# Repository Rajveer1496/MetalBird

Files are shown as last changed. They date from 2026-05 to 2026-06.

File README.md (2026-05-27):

# Current State of Project

### Flight Controller PCB:

<div align="center">

**Top Layer**

<table border="0" cellspacing="0" cellpadding="10">
  <tr>
    <td align="center">
      
    </td>
    <td align="center">
      sm_red_top
    </td>
  </tr>
</table>

---

**Bottom Layer**

<table border="0" cellspacing="0" cellpadding="10">
  <tr>
    <td align="center">
      
    </td>
    <td align="center">
      sm_red_bottom
    </td>
  </tr>
</table>

---

### Flight Controller Schematic:

Schematic

</div>

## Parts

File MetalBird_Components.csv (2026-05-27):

Reference | Qty | Value | Footprint | Link | Datasheet
C1,C3,C4,C6,C8,C16,C22,C23,C25,C18,C20,C1A1 | 12 | 0.1μF | Capacitor_SMD:C_0603_1608Metric | https://www.mouser.in/ProductDetail/YAGEO/CC0603MRY5V9BB104?qs=sGAEpiMZZMuMW9TJLBQkXsl6q5ZT3drfxOCCtIk2mic%3D |  | https://www.amazon.in/Capacitor-36values20pcs-Electronic-Multiplayer-Capacitors/dp/B06XDG3WQX
C5 | 1 | 1nF / 1000pF | Capacitor_SMD:C_0603_1608Metric | https://www.mouser.in/ProductDetail/KYOCERA-AVX/KAM15AR71H102KM
C7 | 1 | 6.8nF / 6800pF | Capacitor_SMD:C_0603_1608Metric | https://www.mouser.in/ProductDetail/Murata-Electronics/GCM188R72A682MA37D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
C9 | 1 | 2.2μF | Capacitor_SMD:C_0603_1608Metric | https://www.mouser.in/ProductDetail/TAIYO-YUDEN/JMK107B7225KAHTR
C10,C12 | 2 | 20pF | Capacitor_SMD:C_0603_1608Metric | https://www.mouser.in/ProductDetail/KEMET/C0603C200G4HACTU?qs=sGAEpiMZZMuMW9TJLBQkXvqpoCCiVPPiX4wV0EC9Nf4%3D
C11,C15 | 2 | 1μF | Capacitor_SMD:C_0603_1608Metric | https://www.mouser.in/ProductDetail/Murata-Electronics/GRM188R61C105KA12D
C13 | 1 | 10pF | Capacitor_SMD:C_0603_1608Metric | https://www.mouser.in/ProductDetail/Vishay-Vitramon/VJ0603A100JXACW1BC
C17 | 1 | 10nF / 0.01μF | Capacitor_SMD:C_0603_1608Metric | https://www.mouser.in/ProductDetail/YAGEO/CC0603KPX7R7BB103
C21 | 1 | 2.2nF / 2200pF | Capacitor_SMD:C_0603_1608Metric | https://www.mouser.in/ProductDetail/KEMET/C0603C222K5RACAUTO7411
C2,C2A1,C14,C19 | 4 | 22µF | Capacitor_SMD:C_1206_3216Metric | https://www.mouser.in/ProductDetail/Samsung-Electro-Mechanics/CL31A226MOCLNNC
C24 | 1 | 100μF | Capacitor_SMD:C_1206_3216Metric | https://www.mouser.in/ProductDetail/Murata-Electronics/GRM31CR61A107MEA8K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
D1,D2 | 2 | LED | LED_SMD:LED_0603_1608Metric | https://robu.in/?s=0603+led&post_type=product
J1 | 1 | Battery Conn | Connector_JST:JST_PH_B2B-PH-K_1x02_P2.00mm_Vertical | https://www.mouser.in/ProductDetail/306-B2BPHKLFSN
J2 | 1 | SWD | Connector_PinHeader_2.54mm:PinHeader_1x04_P2.54mm_Vertical | https://robu.in/product/361030130sg111901-jiln-2-54x3-0machined-pin-header-1x30p-180-l11-96-upper-pinpoint0-60-bottom-pinpoint0-50-au1u-pps/
J3 | 1 | ESC1 | Connector_PinHeader_2.54mm:PinHeader_1x03_P2.54mm_Vertical
J4 | 1 | ESC2 | Connector_PinHeader_2.54mm:PinHeader_1x03_P2.54mm_Vertical
J5 | 1 | ESC3 | Connector_PinHeader_2.54mm:PinHeader_1x03_P2.54mm_Vertical
J6 | 1 | ESC4 | Connector_PinHeader_2.54mm:PinHeader_1x03_P2.54mm_Vertical
J7 | 1 | ELRS Reciver | Connector_PinHeader_2.54mm:PinHeader_1x04_P2.54mm_Vertical
J8 | 1 | USB/UART DEBUG | Connector_PinHeader_2.54mm:PinHeader_1x04_P2.54mm_Vertical
J9 | 1 | Camera Conn | Connector_PinHeader_2.54mm:PinHeader_1x03_P2.54mm_Vertical
J10 | 1 | VTX Conn | Connector_PinHeader_2.54mm:PinHeader_1x03_P2.54mm_Vertical
L1 | 1 | 2.2µH | Inductor_SMD:L_Cenker_CKCS4018 | https://www.mouser.in/ProductDetail/Bourns/SRN4018-2R2M?qs=UvjENeDOEeeZshE%252B%2FY2s8w%3D%3D
MP2331H1 | 1 | ~ | Package_TO_SOT_SMD:SOT-583-8 | https://www.mouser.in/ProductDetail/946-MP2331HGTL-P
Q1 | 1 | PMOS | Package_TO_SOT_SMD:SOT-23 | https://www.mouser.in/ProductDetail/637-MMFTP3401-AQ
R1 | 1 | 604kΩ | Resistor_SMD:R_0603_1608Metric | https://www.mouser.in/ProductDetail/YAGEO/AC0603FR-07604KL
R2,R4,R6 | 3 | 10kΩ | Resistor_SMD:R_0603_1608Metric | https://sharvielectronics.com/product/10k-ohm-1-10-watt-smd-resistor-1-tolerance-rc0603fr-0710kl-0603-package/
R3 | 1 | 20ohm | Resistor_SMD:R_0603_1608Metric | https://www.mouser.in/ProductDetail/YAGEO/RC0603JR-7W20RL
R5 | 1 | 7.68kΩ | Resistor_SMD:R_0603_1608Metric | https://www.mouser.in/ProductDetail/YAGEO/RC0603FR-077K68L
R7 | 1 | 40.2kΩ | Resistor_SMD:R_0603_1608Metric | https://www.mouser.in/ProductDetail/YAGEO/AC0603FR-0740K2L?qs=sGAEpiMZZMtlubZbdhIBIG07xJe44c5AHpWSQ6yK7z4%3D
R8 | 1 | 10K | Resistor_SMD:R_0603_1608Metric | https://sharvielectronics.com/product/10k-ohm-1-10-watt-smd-resistor-1-tolerance-rc0603fr-0710kl-0603-package/
R11 | 1 | 30.9K | Resistor_SMD:R_0603_1608Metric | https://www.mouser.in/ProductDetail/Panasonic/ERJ-PA3D3092V?qs=sGAEpiMZZMtlubZbdhIBIL24R7XL4VFWF2hXjANGU5E%3D
R12 | 1 | 20K | Resistor_SMD:R_0603_1608Metric | https://www.mouser.in/ProductDetail/YAGEO/RT0603FRD0720KL?qs=sGAEpiMZZMtlubZbdhIBIKm0gsRX2fVkuOFal8xbqgw%3D
R13,R14 | 2 | 150 | Resistor_SMD:R_0603_1608Metric | https://sharvielectronics.com/product/150-ohm-1-4w-smd-resistor-pack-of-20-smd-0603/
R15,R16,R17 | 3 | 4.7 K | Resistor_SMD:R_0603_1608Metric | https://sharvielectronics.com/product/4-7k-ohm-1-10-watt-resistor-1-tolerance-0603saf4701t5e-0603-package/
SW1 | 1 | SW_Push_Open | Button_Switch_SMD:SW_SPST_PTS645Sx43SMTR92 | https://www.mouser.in/ProductDetail/506-FSM2JSMATR
U1 | 1 | STM32F411CEUx | Package_DFN_QFN:QFN-48-1EP_7x7mm_P0.5mm_EP5.6x5.6mm | https://robu.in/product/stm32f411ceu6-st-arm-m4-100mhz-ufqfpn-487x7-microcontrollers-mcu-mpu-soc-rohs/
U2 | 1 | AMS1117-3.3 | Package_TO_SOT_SMD:SOT-223-3_TabPin2 | https://robu.in/product/ams1117-3-3v-1a-sot-223-voltage-regulator-ic-pack-of-5-ics/
U3 | 1 | MPU-6050 | Sensor_Motion:InvenSense_QFN-24_4x4mm_P0.5mm | https://robu.in/product/mpu-6050-qfn-24-3-axis-gyro-accelerometer-ic/
U4 | 1 | BMP280 | Package_LGA:Bosch_LGA-8_2x2.5mm_P0.65mm_ClockwisePinNumbering | https://robu.in/product/bmp280-barometric-pressure-and-altitude-sensor-i2c-spi-module/ |  | https://www.mouser.in/ProductDetail/262-BME280
Y1 | 1 | 8MHz | Crystal:Crystal_SMD_3225-4Pin_3.2x2.5mm | https://www.mouser.in/ProductDetail/ECS/ECS-80-12-33-JGN-TR?qs=d0WKAl%252BL4KaVcQK0q%252BTt4Q%3D%3D

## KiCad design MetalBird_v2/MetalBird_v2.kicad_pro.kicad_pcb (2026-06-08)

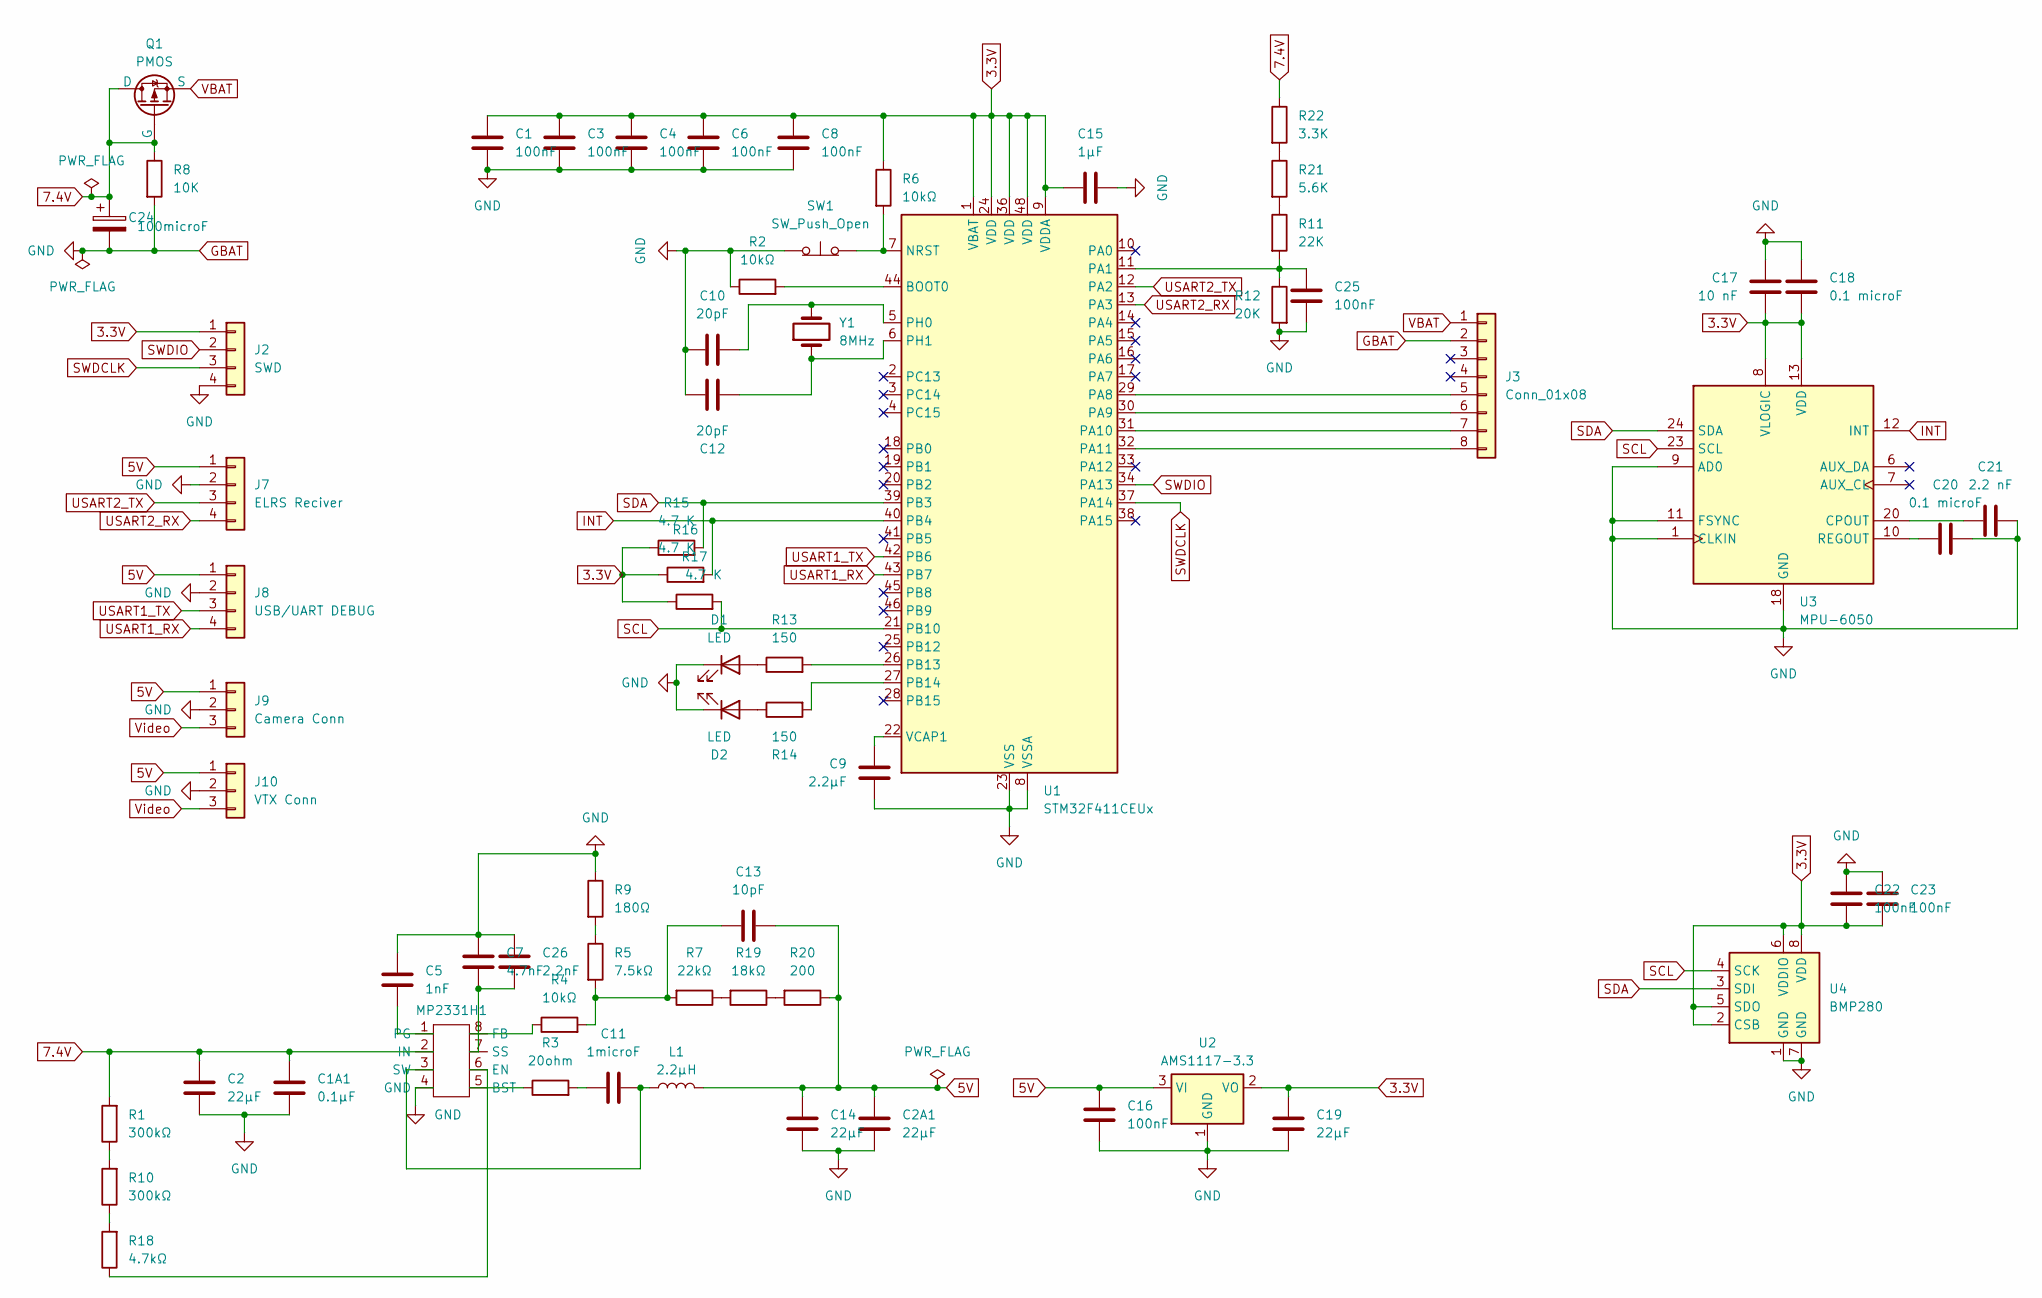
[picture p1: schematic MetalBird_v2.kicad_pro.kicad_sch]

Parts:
C1, C3, C4, C6, C8, C16, C22, C23, C25: 100nF; C_0603_1608Metric
C1A1: 0.1µF; C_0603_1608Metric
C2, C2A1, C14, C19: 22µF; C_1206_3216Metric
C5: 1nF; C_0603_1608Metric
C7: 4.7nF; C_0603_1608Metric
C9: 2.2μF; C_0603_1608Metric
C10, C12: 20pF; C_0603_1608Metric
C11: 1microF; C_0603_1608Metric
C13: 10pF; C_0603_1608Metric
C15: 1μF; C_0603_1608Metric
C17: 10 nF; C_0603_1608Metric
C18, C20: 0.1 microF; C_0603_1608Metric
C21: 2.2 nF; C_0603_1608Metric
C24: 100microF; C_1206_3216Metric
C26: 2.2nF; C_0603_1608Metric
D1, D2: LED; LED_0603_1608Metric
J2: SWD; PinHeader_1x04_P2.54mm_Vertical
J3: Conn_01x08; JST_SH_BM08B-SRSS-TB_1x08-1MP_P1.00mm_Vertical
J7: ELRS Reciver; PinHeader_1x04_P2.54mm_Vertical
J8: USB/UART DEBUG; PinHeader_1x04_P2.54mm_Vertical
J9: Camera Conn; PinHeader_1x03_P2.54mm_Vertical
J10: VTX Conn; PinHeader_1x03_P2.54mm_Vertical
L1: 2.2µH; L_Cenker_CKCS4018
MP2331H1: SOT-583-8
Q1: PMOS; SOT-23
R1, R10: 300kΩ; R_0603_1608Metric
R2, R4, R6: 10kΩ; R_0603_1608Metric
R3: 20ohm; R_0603_1608Metric
R5: 7.5kΩ; R_0603_1608Metric
R7: 22kΩ; R_0603_1608Metric
R8: 10K; R_0603_1608Metric
R9: 180Ω; R_0603_1608Metric
R11: 22K; R_0603_1608Metric
R12: 20K; R_0603_1608Metric
R13, R14: 150; R_0603_1608Metric
R15, R16, R17: 4.7 K; R_0603_1608Metric
R18: 4.7kΩ; R_0603_1608Metric
R19: 18kΩ; R_0603_1608Metric
R20: 200; R_0603_1608Metric
R21: 5.6K; R_0603_1608Metric
R22: 3.3K; R_0603_1608Metric
SW1: SW_Push_Open; SW_SPST_PTS645Sx43SMTR92
U1: STM32F411CEUx; QFN-48-1EP_7x7mm_P0.5mm_EP5.6x5.6mm
U2: AMS1117-3.3; SOT-223-3_TabPin2
U3: MPU-6050; InvenSense_QFN-24_4x4mm_P0.5mm
U4: BMP280; Bosch_LGA-8_2x2.5mm_P0.65mm_ClockwisePinNumbering
Y1: 8MHz; Crystal_SMD_3225-4Pin_3.2x2.5mm

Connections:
3.3V: C1.1, C3.1, C4.1, C6.1, C8.1, C15.2, C17.2, C18.2, C19.1, C22.1, C23.1, J2.1, R6.1, R15.1, R16.1, R17.1, U1.1 (VBAT), U1.9 (VDDA), U1.24 (VDD), U1.36 (VDD), U1.48 (VDD), U2.2 (VO), U3.8 (VLOGIC), U3.13 (VDD), U4.2 (CSB), U4.5 (SDO), U4.6 (VDDIO), U4.8 (VDD)
5V: C2A1.1, C13.2, C14.1, C16.1, J7.1, J8.1, J9.1, J10.1, L1.2, R20.1, U2.3 (VI)
7.4V: C1A1.2, C2.2, C24.1, MP2331H1.2 (IN), Q1.1 (D), Q1.2 (G), R1.2, R8.1, R22.1
GBAT: C1.2, C1A1.1, C2.1, C2A1.2, C3.2, C4.2, C5.2, C6.2, C7.2, C8.2, C9.2, C10.1, C12.1, C14.2, C15.1, C16.2, C17.1, C18.1, C19.2, C20.2, C21.2, C22.2, C23.2, C24.2, C25.2, C26.2, D1.1 (K), D2.1 (K), J2.4, J3.2, J7.2, J8.2, J9.2, J10.2, MP2331H1.4 (GND), R2.1, R8.2, R9.1, R12.2, SW1.1 (A), U1.8 (VSSA), U1.23 (VSS), U1.35 (VSS), U1.47 (VSS), U1.49 (VSS), U2.1 (GND), U3.1 (CLKIN), U3.9 (AD0), U3.11 (FSYNC), U3.18 (GND), U4.1 (GND), U4.7 (GND)
INT: R16.2, U1.40 (PB4), U3.12 (INT)
unnamed: C11.1, R3.2
unnamed: C13.1, R4.2, R5.2, R7.2
unnamed: D1.2 (A), R13.1
unnamed: D2.2 (A), R14.1
unnamed: J3.5, U1.29 (PA8)
unnamed: J3.6, U1.30 (PA9)
unnamed: J3.7, U1.31 (PA10)
unnamed: J3.8, U1.32 (PA11)
unnamed: MP2331H1.5 (BST), R3.1
unnamed: MP2331H1.6 (EN), R18.1
unnamed: MP2331H1.8 (FB), R4.1
unnamed: C5.1, MP2331H1.1 (PG)
unnamed: C7.1, C26.1, MP2331H1.7 (SS)
unnamed: C11.2, L1.1, MP2331H1.3 (SW)
unnamed: R1.1, R10.2
unnamed: R5.1, R9.2
unnamed: R10.1, R18.2
unnamed: R11.1, R21.2
unnamed: R19.1, R20.2
unnamed: R7.1, R19.2
unnamed: R21.1, R22.2
unnamed: R6.2, SW1.2 (B), U1.7 (NRST)
unnamed: R2.2, U1.44 (BOOT0)
unnamed: C25.1, R11.2, R12.1, U1.11 (PA1)
unnamed: R13.2, U1.26 (PB13)
unnamed: R14.2, U1.27 (PB14)
unnamed: C10.2, U1.5 (PH0), Y1.2
unnamed: C12.2, U1.6 (PH1), Y1.1
unnamed: C9.1, U1.22 (VCAP1)
unnamed: C21.1, U3.20 (CPOUT)
unnamed: C20.1, U3.10 (REGOUT)
SCL: R17.2, U1.21 (PB10), U3.23 (SCL), U4.4 (SCK)
SDA: R15.2, U1.39 (PB3), U3.24 (SDA), U4.3 (SDI)
SWDCLK: J2.3, U1.37 (PA14)
SWDIO: J2.2, U1.34 (PA13)
USART1_RX: J8.4, U1.43 (PB7)
USART1_TX: J8.3, U1.42 (PB6)
USART2_RX: J7.4, U1.13 (PA3)
USART2_TX: J7.3, U1.12 (PA2)
VBAT: J3.1, Q1.3 (S)
Video: J9.3, J10.3

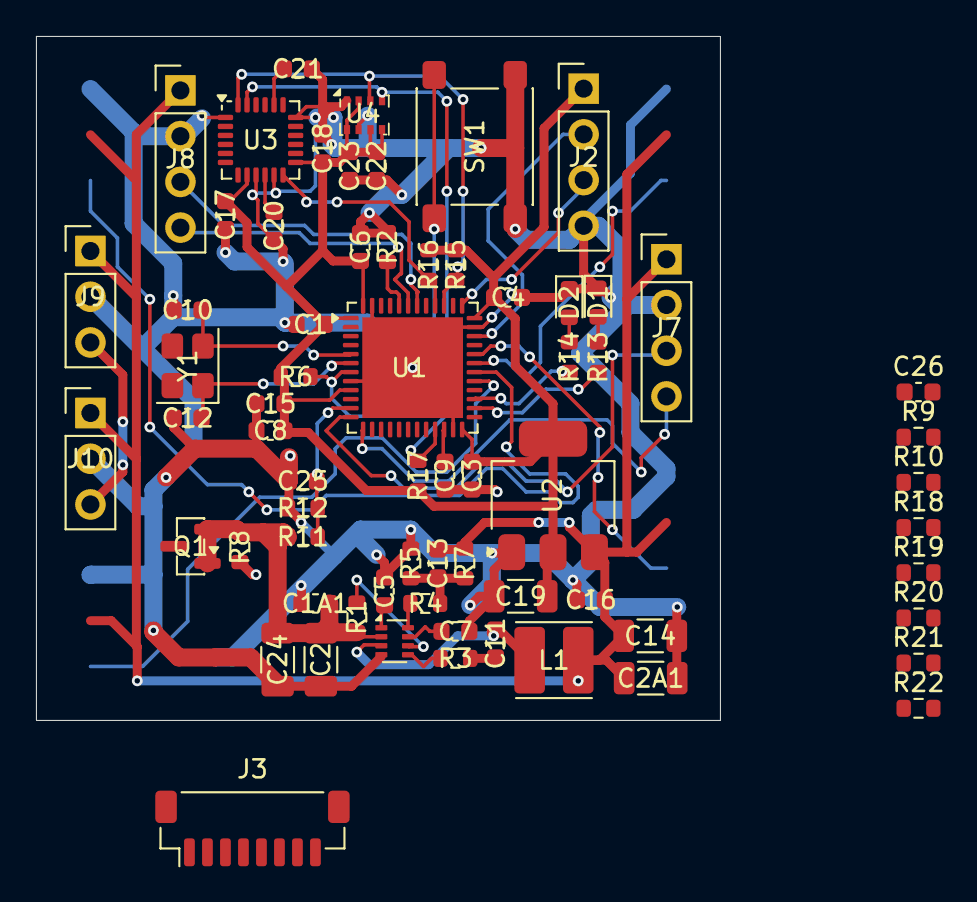
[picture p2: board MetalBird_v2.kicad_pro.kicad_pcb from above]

Board: 2 copper layers, 38.0 x 38.0 mm, 67 parts (0 on the bottom side), 46 nets.

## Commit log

2026-02-26 Early Schematic
    Schematic currently has:
    + All power components connected (with coupling capacitors and pull up/ pull down resistors)
    + 8MHz Oscillator
    [MetalBird.kicad_pcb, MetalBird.kicad_sch]
2026-02-26 Current Status of Project
    + Schematic diagram of Flight controller
2026-03-02 MP2331H Buck converter Symbol
    Created own MP2331H symbol as per its manual.
2026-03-03 Buck Converter Setup (7.4 V -> 5.4 V)
    Values of resistors, capacitors, inductors calculated by taking reference from manual.
    Manual: https://www.monolithicpower.com/en/documentview/productdocument/index/version/2/document_type/Datasheet/lang/en/sku/MP2331HGTL-Z/
    [MetalBird.kicad_sch]
2026-03-04 LDO setup
    [MetalBird.kicad_sch]
2026-03-06 IMU Schematic
    + LDO decoupling capacitor
    [MetalBird.kicad_sch]
2026-05-21 IMU Complete
    Used MPU-6050 Product specification datasheet for reference
    [MetalBird.kicad_sch]
2026-05-22 Flight Controller Schematic Complete
    [MetalBird.kicad_sch]
2026-05-24 Assign Footprints to components
    [MetalBird.kicad_sch]
2026-05-25 PCB Design
    laid out all the components in 36x36mm board
    [MetalBird.kicad_pcb, MetalBird.kicad_sch]
2026-05-26 Routing Complete
    - yet to fix cosmetic stuff (silk overlap)
    [MetalBird.kicad_pcb, MetalBird.kicad_sch]
2026-05-27 Gerber files and components list
    [MetalBird-B_Cu.gbr, MetalBird-B_Mask.gbr, MetalBird-B_Silkscreen.gbr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]
2026-06-03 Simulate Buck-converter
    Simulated in MPSmart
    + Perfectly takes 7.4V input and outputs 5V
2026-06-04 Capacitor and Resistors to standard values
    By arranging multiple caps and resistors in parallel in series
    [MetalBird_v2.kicad_pro.kicad_pcb, MetalBird_v2.kicad_pro.kicad_sch]
2026-06-08 Redesign: 4 in 1 ESC
    - yet to route traces
    [MetalBird_v2.kicad_pro.kicad_pcb, MetalBird_v2.kicad_pro.kicad_sch]
2026-06-22 Buck Converter change
    [MetalBird_v2.kicad_pro.kicad_sch]
2026-07-03 Schematics updates
    [MetalBird_v2.kicad_pro.kicad_sch]
2026-07-12 STM32CubeMX Generated code for Skeleton and Config
2026-08-20 I2C implementation
    TODO from Configure the clock control registers (I2C_CCR)
2026-08-23 I2C init complete
2026-08-25 I2C_SEND function implimentation
2026-09-12 I2C2 Initialization Bug fixes
    1. Alternate Pin function in GPIO_MODER
    2. External 2.2 K ohm pullup resistors (according to max RISE time)
    3. Pin function Must be alternated before starting peripheral
    4. Stack corruption in MACROS (Missing REG POPs)
    [MetalBird_v2.kicad_pro.kicad_sch]
2026-09-23 MPU6050 receive fix
    Corrected I2C controller receiver sequence according to STM32's reference manual.
2026-09-24 Expand Debug capabilities
    + I2C2 MPU6050 Working : Tested on WHO AM I
    - Yet to fix unallignment in i2c_mpu6050_receive
    [MetalBird_v2.kicad_pro.kicad_sch]
